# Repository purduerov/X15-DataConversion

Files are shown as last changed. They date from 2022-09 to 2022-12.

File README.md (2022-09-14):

# Readme for X15-DataConversion

Whenever you make a new part, download the datasheet and save it here _**and**_ with the part in the parts library

Always pull other people's changes before beginning to work
`git pull`

Be sure to push your changes after  working on them. Run:
1. `git add .` to add any files in this directory or a subdirectory
or `git add -u` to add any modified files
2. (Optional) `git clean -nX` to see what ignored files can be removed
	`git clean -fX` removes ignored files (Eagle backups)
3. `git commit -m "helpful commit message"` with a description of the work that you did
4. `git push` to push your work to github

Other helpful commands
* `git status` says information about modified and staged files
* `git log` shows the recent commits of the repository
* `git log filename.extension` show the recent commits for just that file
* `git checkout first-couple-letter-of-commit-id` lets you go back to a previous version
* `git checkout master` brings you back to the latest commit
* `git tag` lists the tags
* `git tag -a orderX -m "the version of the board placed for the X'th order"` tag a specific commit
* `git push --tags` needed to push tags to remote
* `git show orderX` show the commit log for the given tag
* `git checkout orderX` go back and interact with the files at the tagged commit

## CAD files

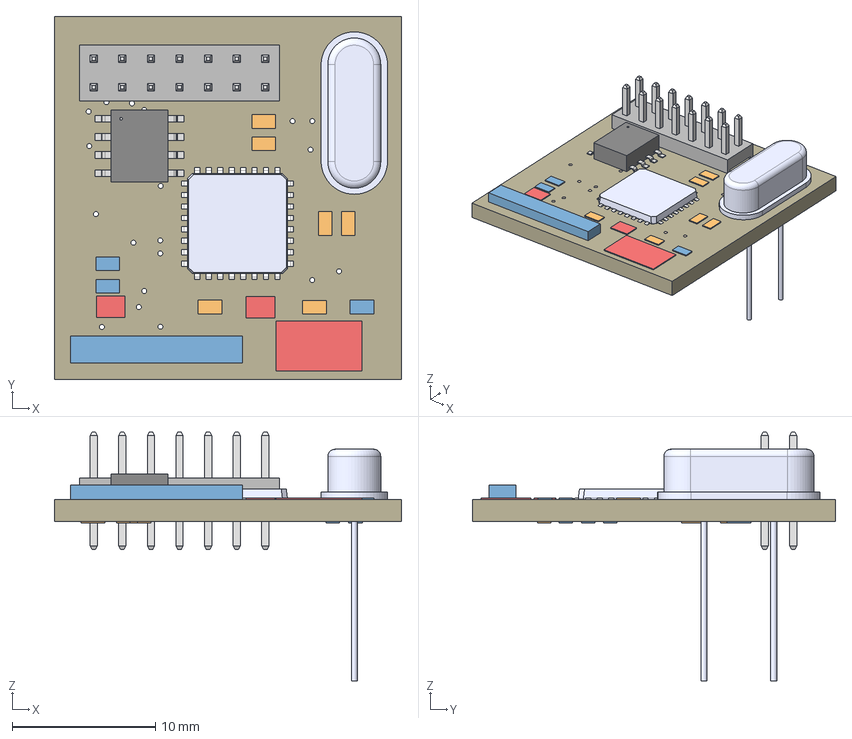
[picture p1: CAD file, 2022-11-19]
X15-DataConversion(5).step
24.3 x 25.4 x 17.4 mm
Board
STM32F042K6T6
18pF x 8
MOMENTARY-SWITCH-SPST-SMD-6.0X3.5MM
3V3 -SWCLK-GND-SWDIO- NRST
TMM-107-01-T-D_pins2
TMM-107-01-T-D_pins1
TMM-107-01-T-D_body
MAX3058ASA+
ECS-80-18-4X
LSM0805452VLED_05452V_VCC x 2

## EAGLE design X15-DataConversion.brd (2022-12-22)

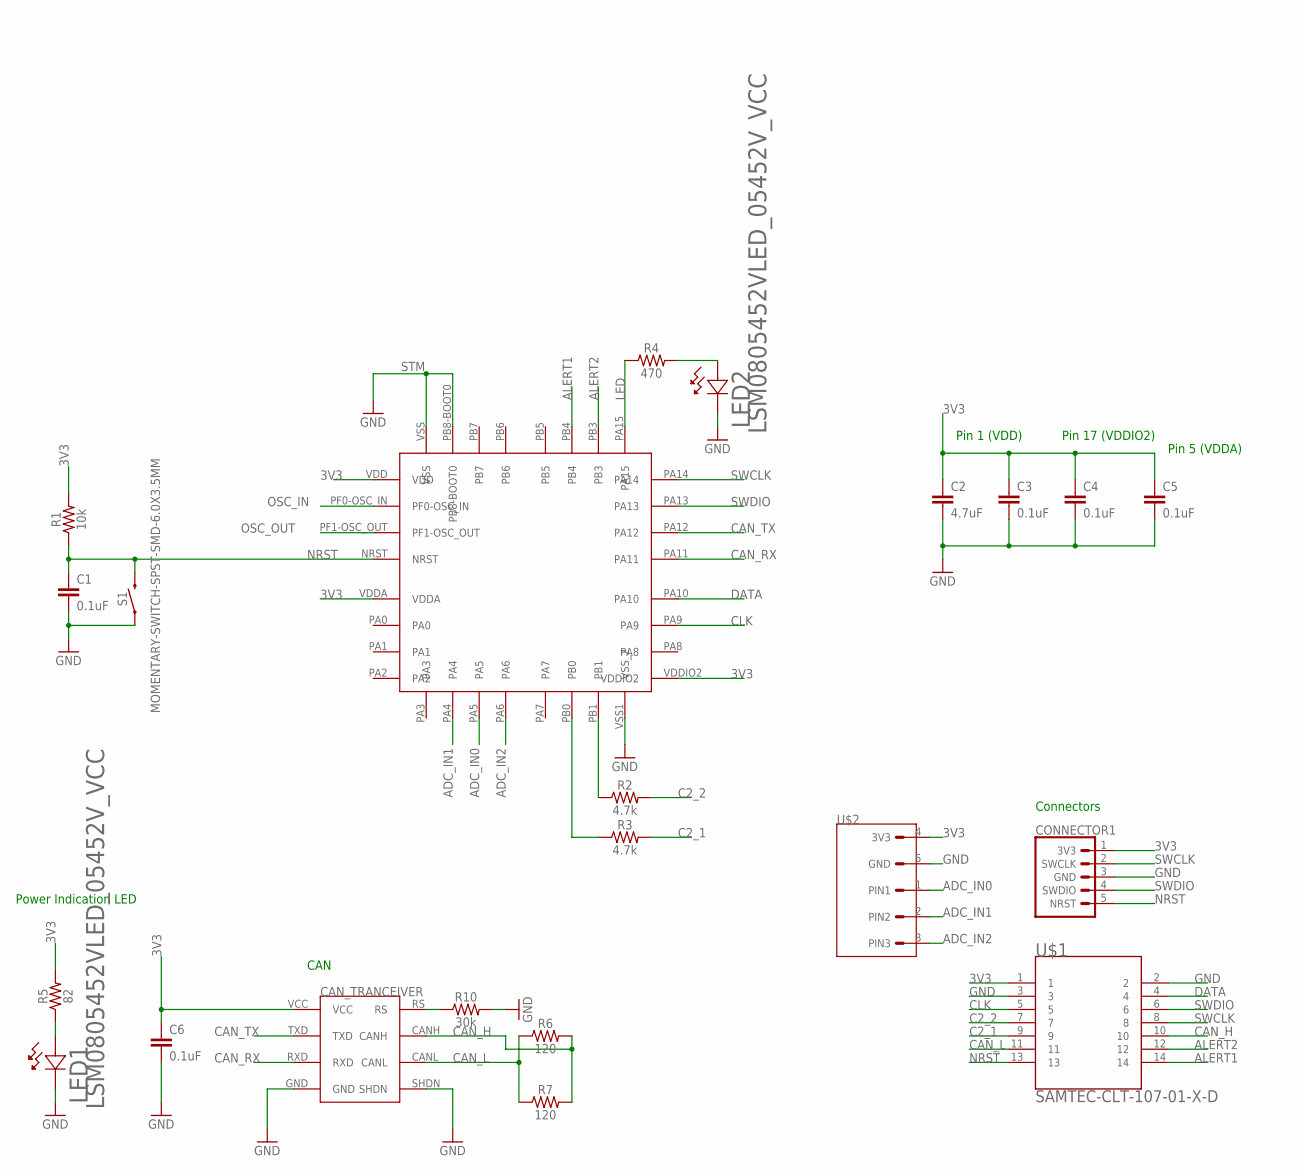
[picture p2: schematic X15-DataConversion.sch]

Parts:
C1, C3, C4, C5, C6: 0.1uF; 0603
C2: 4.7uF; 0603
CAN_TRANCEIVER: MAX3058ASA+
CONNECTOR1: 3V3 -SWCLK-GND-SWDIO- NRST; 1X05
LED1, LED2: LSM0805452VLED_05452V_VCC; LED_05452V_VCC
R1: 10k; 0603
R2, R3: 4.7k; 0603
R4: 470; 0603
R5: 82; 0603
R6, R7: 120; 0603
R10: 30k; 0603
S1: MOMENTARY-SWITCH-SPST-SMD-6.0X3.5MM; TACTILE_SWITCH_SMD_6.0X3.5MM
STM: STM32F042K6T6
U$1: BACKPLANE->DATACONV; SAMTEC-CLT-107-01-X-D-BACKPLANE
U$2: STM_CONN; 1X05

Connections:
3V3: C2.1, C3.1, C4.1, C5.1, C6.1, CAN_TRANCEIVER.VCC, CONNECTOR1.1 (3V3), R1.2, R5.2, STM.VDD, STM.VDDA, STM.VDDIO2, U$1.1, U$2.4 (3V3)
ADC_IN0: STM.PA5, U$2.1 (PIN1)
ADC_IN1: STM.PA4, U$2.2 (PIN2)
ADC_IN2: STM.PA6, U$2.3 (PIN3)
ALERT1: STM.PB4, U$1.14
ALERT2: STM.PB3, U$1.12
C2_1: R3.2, U$1.9
C2_2: R2.2, U$1.7
CAN_H: CAN_TRANCEIVER.CANH, R6.2, R7.2, U$1.10
CAN_L: CAN_TRANCEIVER.CANL, R6.1, R7.1, U$1.11
CAN_RX: CAN_TRANCEIVER.RXD, STM.PA11
CAN_TX: CAN_TRANCEIVER.TXD, STM.PA12
CLK: STM.PA9, U$1.5
DATA: STM.PA10, U$1.4
GND: C1.2, C2.2, C3.2, C4.2, C5.2, C6.2, CAN_TRANCEIVER.GND, CAN_TRANCEIVER.SHDN, CONNECTOR1.3 (GND), LED1.2, LED2.2, R10.2, S1.1, STM.PB8-BOOT0, STM.VSS, STM.VSS1 (VSS_2), U$1.2, U$1.3, U$2.5 (GND)
LED: R4.1, STM.PA15
unnamed: LED1.1, R5.1
unnamed: CAN_TRANCEIVER.RS, R10.1
unnamed: R2.1, STM.PB1
unnamed: R3.1, STM.PB0
unnamed: LED2.1, R4.2
NRST: C1.1, CONNECTOR1.5 (NRST), R1.1, S1.2, STM.NRST, U$1.13
OSC_IN: STM.PF0-OSC_IN
OSC_OUT: STM.PF1-OSC_OUT
SWCLK: CONNECTOR1.2 (SWCLK), STM.PA14, U$1.8
SWDIO: CONNECTOR1.4 (SWDIO), STM.PA13, U$1.6

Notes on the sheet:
Power Indication LED
Connectors
CAN
Pin 1 (VDD)
Pin 17 (VDDIO2)
Pin 5 (VDDA)

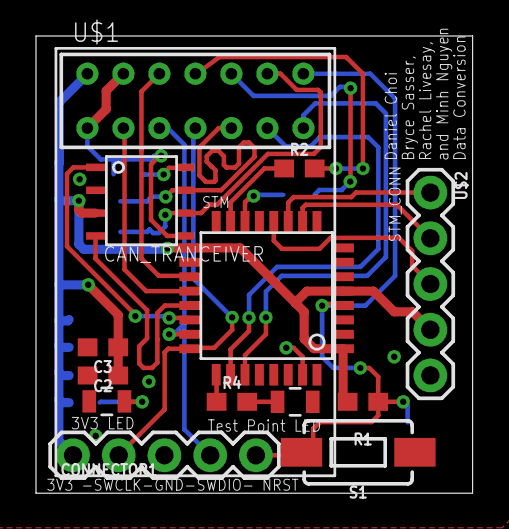
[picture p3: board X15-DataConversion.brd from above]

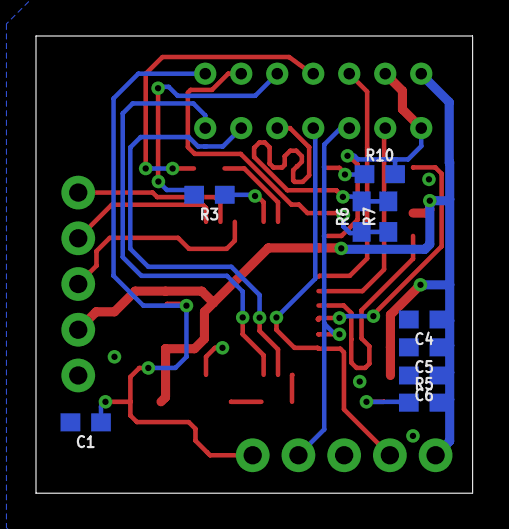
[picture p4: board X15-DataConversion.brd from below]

Board: 2 copper layers, 24.3 x 25.4 mm, 22 parts (9 on the bottom side), 24 nets.

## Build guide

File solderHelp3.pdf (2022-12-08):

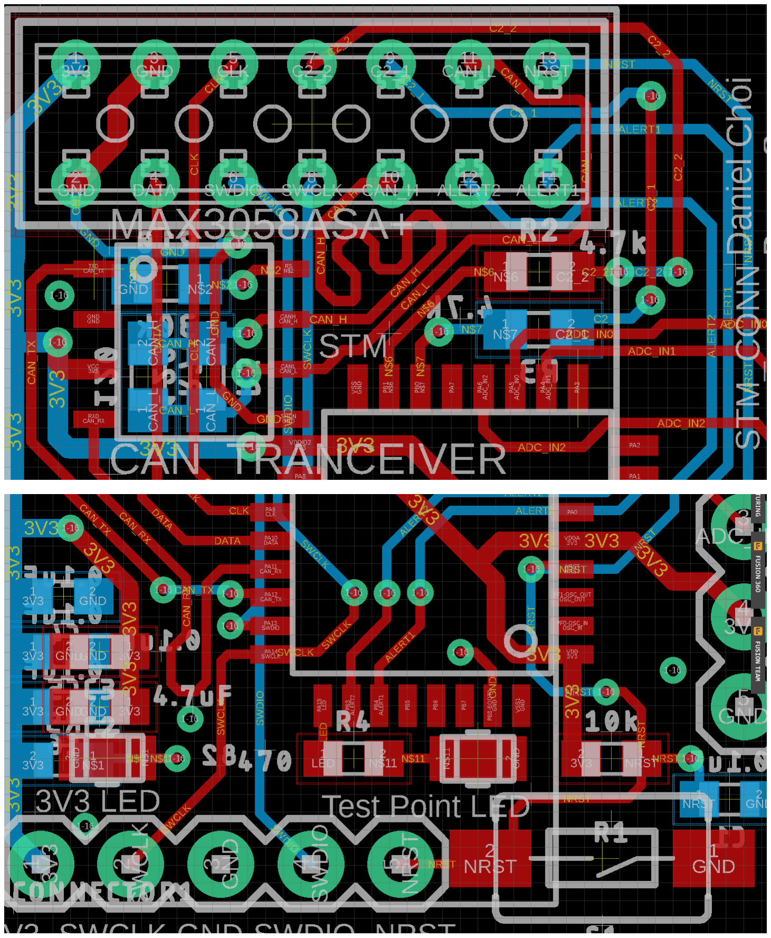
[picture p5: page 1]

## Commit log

2022-10-12 basic schematic finished
2022-10-15 schematic actually finished now
    [X15-DataConversion.brd, X15-DataConversion.sch]
2022-10-15 added oscillator
    [X15-DataConversion.brd, X15-DataConversion.sch]
2022-10-19 board dimensions
    [X15-DataConversion.brd]
2022-10-19 oscillator resistor and capacitor labels
    [X15-DataConversion.brd, X15-DataConversion.sch]
2022-10-20 replaced oscillator with same one as on Pi Shield
    [X15-DataConversion.brd, X15-DataConversion.sch]
2022-10-20 starting layout
    [X15-DataConversion.brd]
2022-10-22 starting wiring
    [X15-DataConversion.brd, X15-DataConversion.sch]
2022-10-29 layout mostly done
    [X15-DataConversion.brd, X15-DataConversion.sch]
2022-10-29 fixing board layout
    [X15-DataConversion.brd, X15-DataConversion.sch]
2022-11-02 made can lines sameish length
    [X15-DataConversion.brd]
2022-11-05 cleaning up board layout
    [X15-DataConversion.brd, X15-DataConversion.sch]
2022-11-11 step file
    [X15-DataConversion.brd, X15-DataConversion.step]
2022-11-12 .gitignore file from last year + new step file
    [X15-DataConversion(3).step, X15-DataConversion.brd, X15-DataConversion.step]
2022-11-19 alumni review changes
    [X15-DataConversion(3).step, X15-DataConversion(5).step, X15-DataConversion.brd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]
2022-11-19 fixed drc error
    [X15-DataConversion.brd]
2022-12-01 removed oscillator and fixed trace widths
    [X15-DataConversion.brd, X15-DataConversion.sch]
2022-12-03 added 5 pin connector
    [X15-DataConversion.brd, X15-DataConversion.sch]
2022-12-03 fixed some trace lengths and widths and angles
    [X15-DataConversion.brd]
2022-12-08 used the wrong connector so fixed that
    [X15-DataConversion.brd, X15-DataConversion.sch]
2022-12-22 Fix label position
    [X15-DataConversion.brd]

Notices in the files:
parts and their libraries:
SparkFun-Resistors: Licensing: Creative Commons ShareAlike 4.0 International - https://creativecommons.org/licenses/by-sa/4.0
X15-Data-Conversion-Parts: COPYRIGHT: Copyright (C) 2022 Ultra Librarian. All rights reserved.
